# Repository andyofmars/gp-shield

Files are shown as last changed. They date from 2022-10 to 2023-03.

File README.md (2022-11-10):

# gp-shield
## A general purpose arduino-compatible shield for UTAS projects

<p float="left">
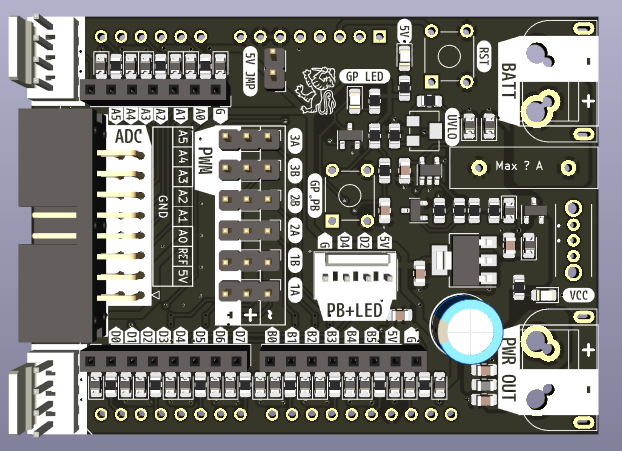
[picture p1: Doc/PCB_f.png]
  
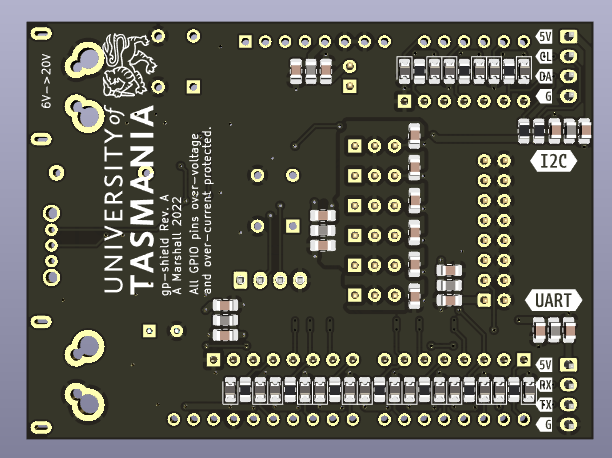
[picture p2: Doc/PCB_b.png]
   
</p>

## Overview
The shield is intended to be used as a general purpose shield for Arduino Uno compatible microcontroller development boards or as an interface between a development board and other custom electronics.

From previous projects we have identified multiple common issues when interfacing with common microcontroller development boards including the Arduino UNO and Xplained Mini series of development boards.
- Many development boards are sensitive to fluctuations in the power supply during programming and can become 'bricked'.
- A lack of protection on the Vin and 5V lines when being powered from a shield or other electronics makes them susceptible to damage.
- Due to the lack of protection and the large number of exposed GPIO pins it is easy to draw too much current or apply an overvoltage condition which will damage the microcontroller.

**See [Rugged Circuits](https://www.rugged-circuits.com/10-ways-to-destroy-an-arduino) for more detail on common issues with the Arduino UNO.**

To resolve these issue for most use cases and provide general functionality commonly needed in electronics projects we have developed the gp-shield to be used as the standard method of interfacing with Arduino UNO compatible development boards.

## Features
- Can be powered from external battery (~6V - 20V)
- On-board power supply with overvoltage (25V?), overcurrent (6A), and reverse polarity protection as well as adjustable undervoltage lockout and an on-board or external power switch.
- Onboard 5V regulation (up to 1A output) with circuitry with a jumper to isolate 5V from the development board.
- Overvoltage (~5.1V) and overcurrent (~30mA) protection on all GPIO pins when using the on-board headers and connectors.
- ICD style analogue outputs, PORTD and PORTB GPIO pins, 6 servo-style PWM outputs, UART, SPI and a high current output for powereing other electronics from the same supply with all of the built in seafty features.
- On-board microcontroller reset button
- On-board general purpose LED and push button

The board itself is 2-layers with double-sided load. All components use footprints suitable for hand-soldering. It is intended to be assembled in-house using pick-and-place machine and reflow soldering.

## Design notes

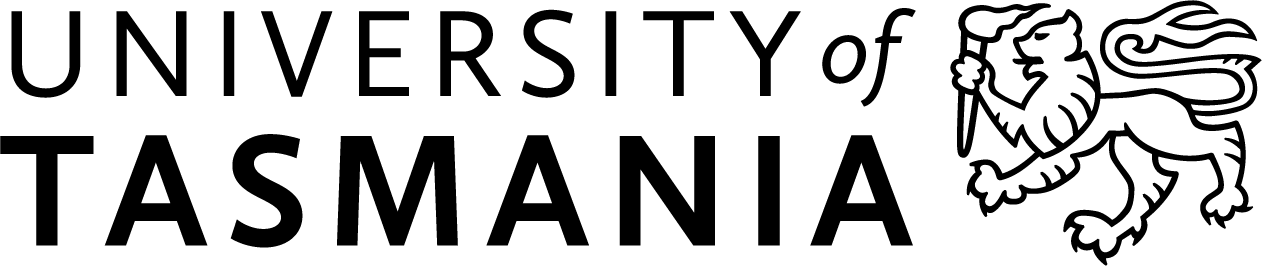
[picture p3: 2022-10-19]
Hardware/Electrical/gp-shield/Resource/UniTas_BM_H_Pos_Mono_RGB_2021@2x.png

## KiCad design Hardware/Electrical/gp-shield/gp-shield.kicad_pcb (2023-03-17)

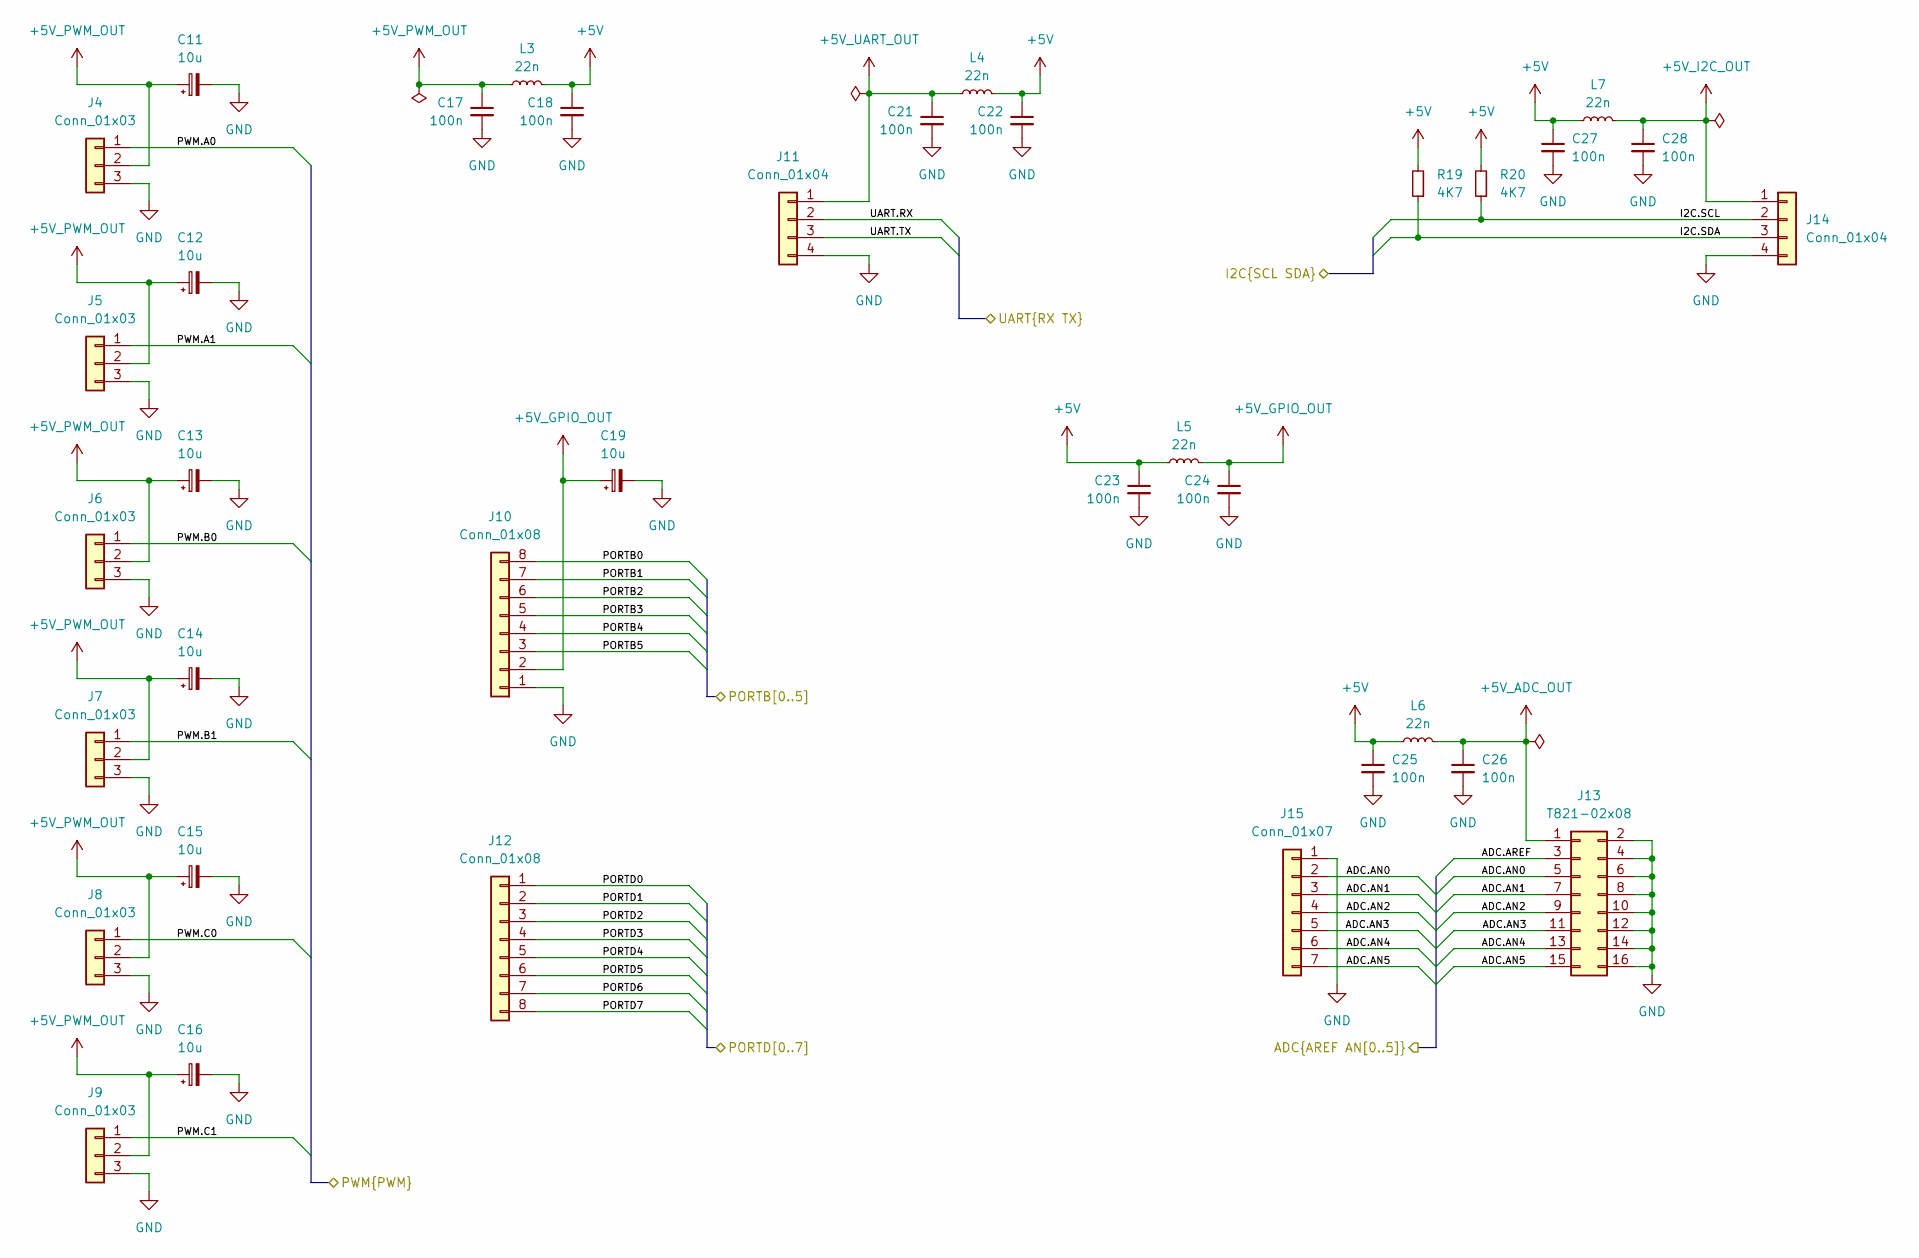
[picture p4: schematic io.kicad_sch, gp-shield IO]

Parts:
C11, C12, C13, C14, C15, C16, C19: 10u; C_0805_2012Metric_Pad1.18x1.45mm_HandSolder
C17, C18, C21, C22, C23, C24, C25, C26, C27, C28: 100n; C_0805_2012Metric_Pad1.18x1.45mm_HandSolder
J4, J5, J6, J7, J8, J9: Conn_01x03; PinHeader_1x03_P2.54mm_Vertical
J10, J12: Conn_01x08; PinSocket_1x08_P2.54mm_Vertical
J11, J14: Conn_01x04; Molex_KK-254_AE-6410-04A_1x04_P2.54mm_Vertical
J13: T821-02x08; IDC-Header_2x08_P2.54mm_Horizontal
J15: Conn_01x07; PinSocket_1x07_P2.54mm_Vertical
L3, L4, L5, L6, L7: 22n; L_0805_2012Metric_Pad1.15x1.40mm_HandSolder
R19, R20: 4K7; R_0805_2012Metric_Pad1.20x1.40mm_HandSolder

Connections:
+5V: C18.1, C22.1, C23.1, C25.1, C27.1, L3.1, L4.1, L5.2, L6.1, L7.1, R19.2, R20.2; also elsewhere on the board
+5V_ADC_OUT: C26.1, J13.1, L6.2
+5V_GPIO_OUT: C19.1, C24.1, J10.2, L5.1
+5V_I2C_OUT: C28.1, J14.1, L7.2
+5V_PWM_OUT: C11.1, C12.1, C13.1, C14.1, C15.1, C16.1, C17.1, J4.2, J5.2, J6.2, J7.2, J8.2, J9.2, L3.2
+5V_UART_OUT: C21.1, J11.1, L4.2
/IO/ADC.AN0: J13.5, J15.2; also elsewhere on the board
/IO/ADC.AN1: J13.7, J15.3; also elsewhere on the board
/IO/ADC.AN2: J13.9, J15.4; also elsewhere on the board
/IO/ADC.AN3: J13.11, J15.5; also elsewhere on the board
/IO/ADC.AN4: J13.13, J15.6; also elsewhere on the board
/IO/ADC.AN5: J13.15, J15.7; also elsewhere on the board
/IO/ADC.AREF: J13.3; also elsewhere on the board
/IO/I2C.SCL: J14.2, R20.1; also elsewhere on the board
/IO/I2C.SDA: J14.3, R19.1; also elsewhere on the board
/IO/PORTB0: J10.8; also elsewhere on the board
/IO/PORTB1: J10.7; also elsewhere on the board
/IO/PORTB2: J10.6; also elsewhere on the board
/IO/PORTB3: J10.5; also elsewhere on the board
/IO/PORTB4: J10.4; also elsewhere on the board
/IO/PORTB5: J10.3; also elsewhere on the board
/IO/PORTD0: J12.1; also elsewhere on the board
/IO/PORTD1: J12.2; also elsewhere on the board
/IO/PORTD2: J12.3; also elsewhere on the board
/IO/PORTD3: J12.4; also elsewhere on the board
/IO/PORTD4: J12.5; also elsewhere on the board
/IO/PORTD5: J12.6; also elsewhere on the board
/IO/PORTD6: J12.7; also elsewhere on the board
/IO/PORTD7: J12.8; also elsewhere on the board
/IO/PWM.A0: J4.1; also elsewhere on the board
/IO/PWM.A1: J5.1; also elsewhere on the board
/IO/PWM.B0: J6.1; also elsewhere on the board
/IO/PWM.B1: J7.1; also elsewhere on the board
/IO/PWM.C0: J8.1; also elsewhere on the board
/IO/PWM.C1: J9.1; also elsewhere on the board
/IO/UART.RX: J11.2; also elsewhere on the board
/IO/UART.TX: J11.3; also elsewhere on the board
GND: C11.2, C12.2, C13.2, C14.2, C15.2, C16.2, C17.2, C18.2, C19.2, C21.2, C22.2, C23.2, C24.2, C25.2, C26.2, C27.2, C28.2, J4.3, J5.3, J6.3, J7.3, J8.3, J9.3, J10.1, J11.4, J13.2, J13.4, J13.6, J13.8, J13.10, J13.12, J13.14, J13.16, J14.4, J15.1; also elsewhere on the board

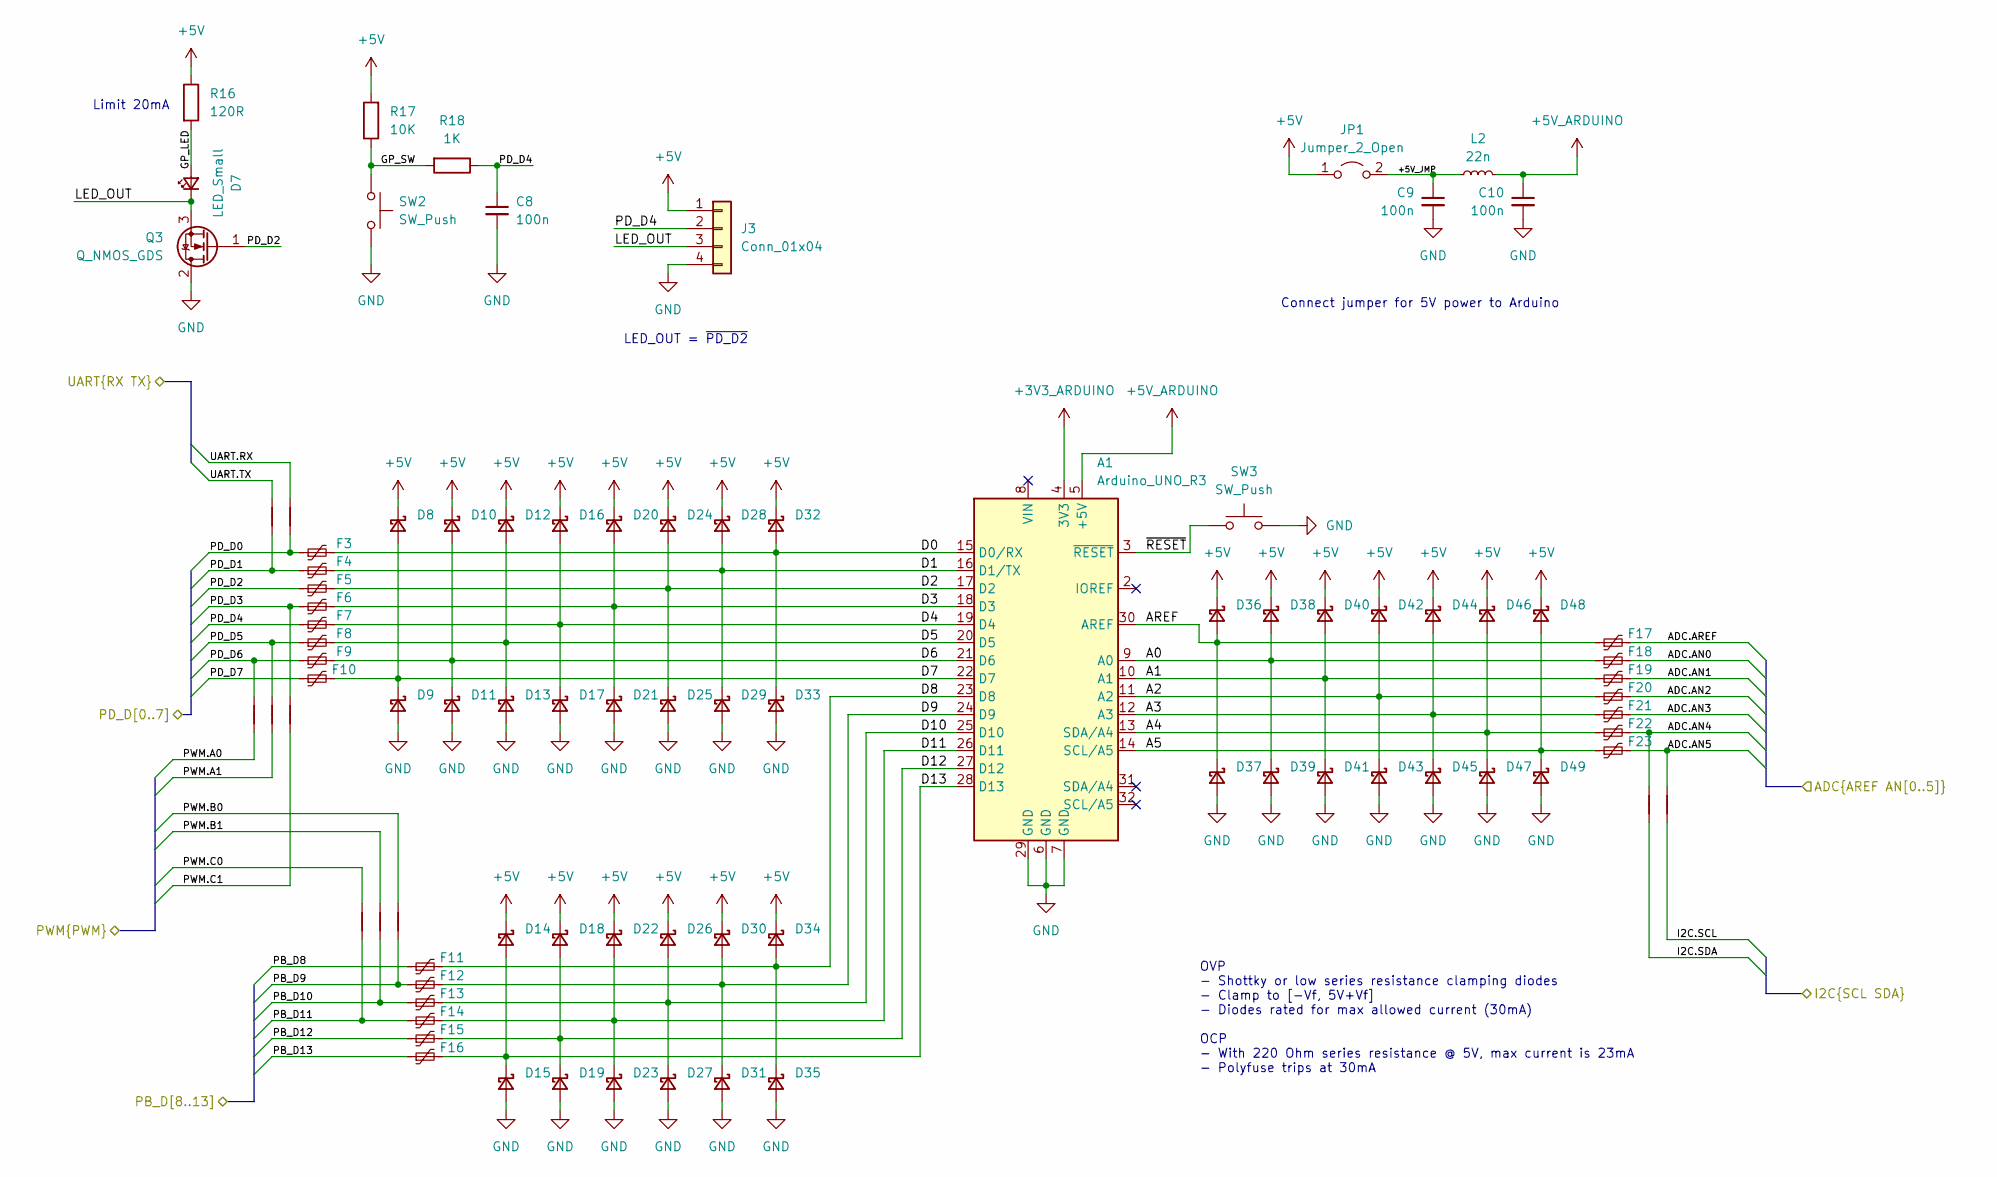
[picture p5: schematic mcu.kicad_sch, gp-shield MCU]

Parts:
A1: Arduino_UNO_R3
C8, C9, C10: 100n; C_0805_2012Metric_Pad1.18x1.45mm_HandSolder
D7: LED_Small; LED_0805_2012Metric_Pad1.15x1.40mm_HandSolder
D8, D9, D10, D11, D12, D13, D14, D15, D16, D17, D18, D19, D20, D21, D22, D23, D24, D25, D26, D27, D28, D29, D30, D31, D32, D33, D34, D35, D36, D37, D38, D39, D40, D41, D42, D43, D44, D45, D46, D47, D48, D49: D_Schottky_Small; D_0805_2012Metric_Pad1.15x1.40mm_HandSolder
F3, F4, F5, F6, F7, F8, F9, F10, F11, F12, F13, F14, F15, F16, F17, F18, F19, F20, F21, F22, F23: Polyfuse_Small; Fuse_0805_2012Metric_Pad1.15x1.40mm_HandSolder; Digikey Part No PRG18BB221MB1RB
J3: Conn_01x04; Molex_KK-254_AE-6410-04A_1x04_P2.54mm_Vertical
JP1: Jumper_2_Open; PinHeader_1x02_P2.54mm_Vertical
L2: 22n; L_0805_2012Metric_Pad1.15x1.40mm_HandSolder
NT1, NT2, NT3, NT4, NT5, NT6, NT7, NT8, NT9, NT10: NetTie_2; NetTie-2_THT_Pad0.3mm
Q3: Q_NMOS_GDS; SOT-23
R16: 120R; R_0805_2012Metric_Pad1.20x1.40mm_HandSolder
R17: 10K; R_0805_2012Metric_Pad1.20x1.40mm_HandSolder
R18: 1K; R_0805_2012Metric_Pad1.20x1.40mm_HandSolder
SW2, SW3: SW_Push; SW_TH_Tactile_Omron_B3F-10xx

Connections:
+3V3_ARDUINO: A1.4 (3V3)
+5V: D8.1 (K), D10.1 (K), D12.1 (K), D14.1 (K), D16.1 (K), D18.1 (K), D20.1 (K), D22.1 (K), D24.1 (K), D26.1 (K), D28.1 (K), D30.1 (K), D32.1 (K), D34.1 (K), D36.1 (K), D38.1 (K), D40.1 (K), D42.1 (K), D44.1 (K), D46.1 (K), D48.1 (K), J3.1, JP1.1 (A), R16.1, R17.2; also elsewhere on the board
+5V_ARDUINO: A1.5 (+5V), C10.1, L2.1
/IO/ADC.AN0: F18.2; also elsewhere on the board
/IO/ADC.AN1: F19.2; also elsewhere on the board
/IO/ADC.AN2: F20.2; also elsewhere on the board
/IO/ADC.AN3: F21.2; also elsewhere on the board
/IO/ADC.AN4: F22.2, NT9.2; also elsewhere on the board
/IO/ADC.AN5: F23.2, NT10.2; also elsewhere on the board
/IO/ADC.AREF: F17.2; also elsewhere on the board
/IO/I2C.SCL: NT10.1; also elsewhere on the board
/IO/I2C.SDA: NT9.1; also elsewhere on the board
/IO/PORTB0: F11.1; also elsewhere on the board
/IO/PORTB1: F12.1, NT8.1; also elsewhere on the board
/IO/PORTB2: F13.1, NT7.1; also elsewhere on the board
/IO/PORTB3: F14.1, NT6.1; also elsewhere on the board
/IO/PORTB4: F15.1; also elsewhere on the board
/IO/PORTB5: F16.1; also elsewhere on the board
/IO/PORTD0: F3.1, NT4.1; also elsewhere on the board
/IO/PORTD1: F4.1, NT2.1; also elsewhere on the board
/IO/PORTD2: F5.1, Q3.1 (G); also elsewhere on the board
/IO/PORTD3: F6.1, NT5.2; also elsewhere on the board
/IO/PORTD4: C8.1, F7.1, J3.2, R18.1; also elsewhere on the board
/IO/PORTD5: F8.1, NT3.2; also elsewhere on the board
/IO/PORTD6: F9.1, NT1.2; also elsewhere on the board
/IO/PORTD7: F10.1; also elsewhere on the board
/IO/PWM.A0: NT1.1; also elsewhere on the board
/IO/PWM.A1: NT3.1; also elsewhere on the board
/IO/PWM.B0: NT8.2; also elsewhere on the board
/IO/PWM.B1: NT7.2; also elsewhere on the board
/IO/PWM.C0: NT6.2; also elsewhere on the board
/IO/PWM.C1: NT5.1; also elsewhere on the board
/IO/UART.RX: NT4.2; also elsewhere on the board
/IO/UART.TX: NT2.2; also elsewhere on the board
/MCU/+5V_JMP: C9.1, JP1.2 (B), L2.2
/MCU/A0: A1.9 (A0), D38.2 (A), D39.1 (K), F18.1
/MCU/A1: A1.10 (A1), D40.2 (A), D41.1 (K), F19.1
/MCU/A2: A1.11 (A2), D42.2 (A), D43.1 (K), F20.1
/MCU/A3: A1.12 (A3), D44.2 (A), D45.1 (K), F21.1
/MCU/A4: A1.13 (SDA/A4), D46.2 (A), D47.1 (K), F22.1
/MCU/A5: A1.14 (SCL/A5), D48.2 (A), D49.1 (K), F23.1
/MCU/AREF: A1.30 (AREF), D36.2 (A), D37.1 (K), F17.1
/MCU/D0: A1.15 (D0/RX), D32.2 (A), D33.1 (K), F3.2
/MCU/D1: A1.16 (D1/TX), D28.2 (A), D29.1 (K), F4.2
/MCU/D2: A1.17 (D2), D24.2 (A), D25.1 (K), F5.2
/MCU/D3: A1.18 (D3), D20.2 (A), D21.1 (K), F6.2
/MCU/D4: A1.19 (D4), D16.2 (A), D17.1 (K), F7.2
/MCU/D5: A1.20 (D5), D12.2 (A), D13.1 (K), F8.2
/MCU/D6: A1.21 (D6), D10.2 (A), D11.1 (K), F9.2
/MCU/D7: A1.22 (D7), D8.2 (A), D9.1 (K), F10.2
/MCU/D8: A1.23 (D8), D34.2 (A), D35.1 (K), F11.2
/MCU/D9: A1.24 (D9), D30.2 (A), D31.1 (K), F12.2
/MCU/D10: A1.25 (D10), D26.2 (A), D27.1 (K), F13.2
/MCU/D11: A1.26 (D11), D22.2 (A), D23.1 (K), F14.2
/MCU/D12: A1.27 (D12), D18.2 (A), D19.1 (K), F15.2
/MCU/D13: A1.28 (D13), D14.2 (A), D15.1 (K), F16.2
/MCU/GP_LED: D7.2 (A), R16.2
/MCU/GP_SW: R17.1, R18.2, SW2.1
/MCU/LED_OUT: D7.1 (K), J3.3, Q3.3 (S)
/MCU/~RESET: A1.3 (~RESET), SW3.1
GND: A1.6 (GND), A1.7 (GND), A1.29 (GND), C8.2, C9.2, C10.2, D9.2 (A), D11.2 (A), D13.2 (A), D15.2 (A), D17.2 (A), D19.2 (A), D21.2 (A), D23.2 (A), D25.2 (A), D27.2 (A), D29.2 (A), D31.2 (A), D33.2 (A), D35.2 (A), D37.2 (A), D39.2 (A), D41.2 (A), D43.2 (A), D45.2 (A), D47.2 (A), D49.2 (A), J3.4, Q3.2 (D), SW2.2, SW3.2; also elsewhere on the board

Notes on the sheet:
LED_OUT = ~{PD_D2}
OVP - Shottky or low series resistance clamping diodes - Clamp to [-Vf, 5V+Vf] - Diodes rated for max allowed current (30mA) OCP - With 220 Ohm series resistance @ 5V, max current is 23mA - Polyfuse trips at 30mA
Limit 20mA
Connect jumper for 5V power to Arduino

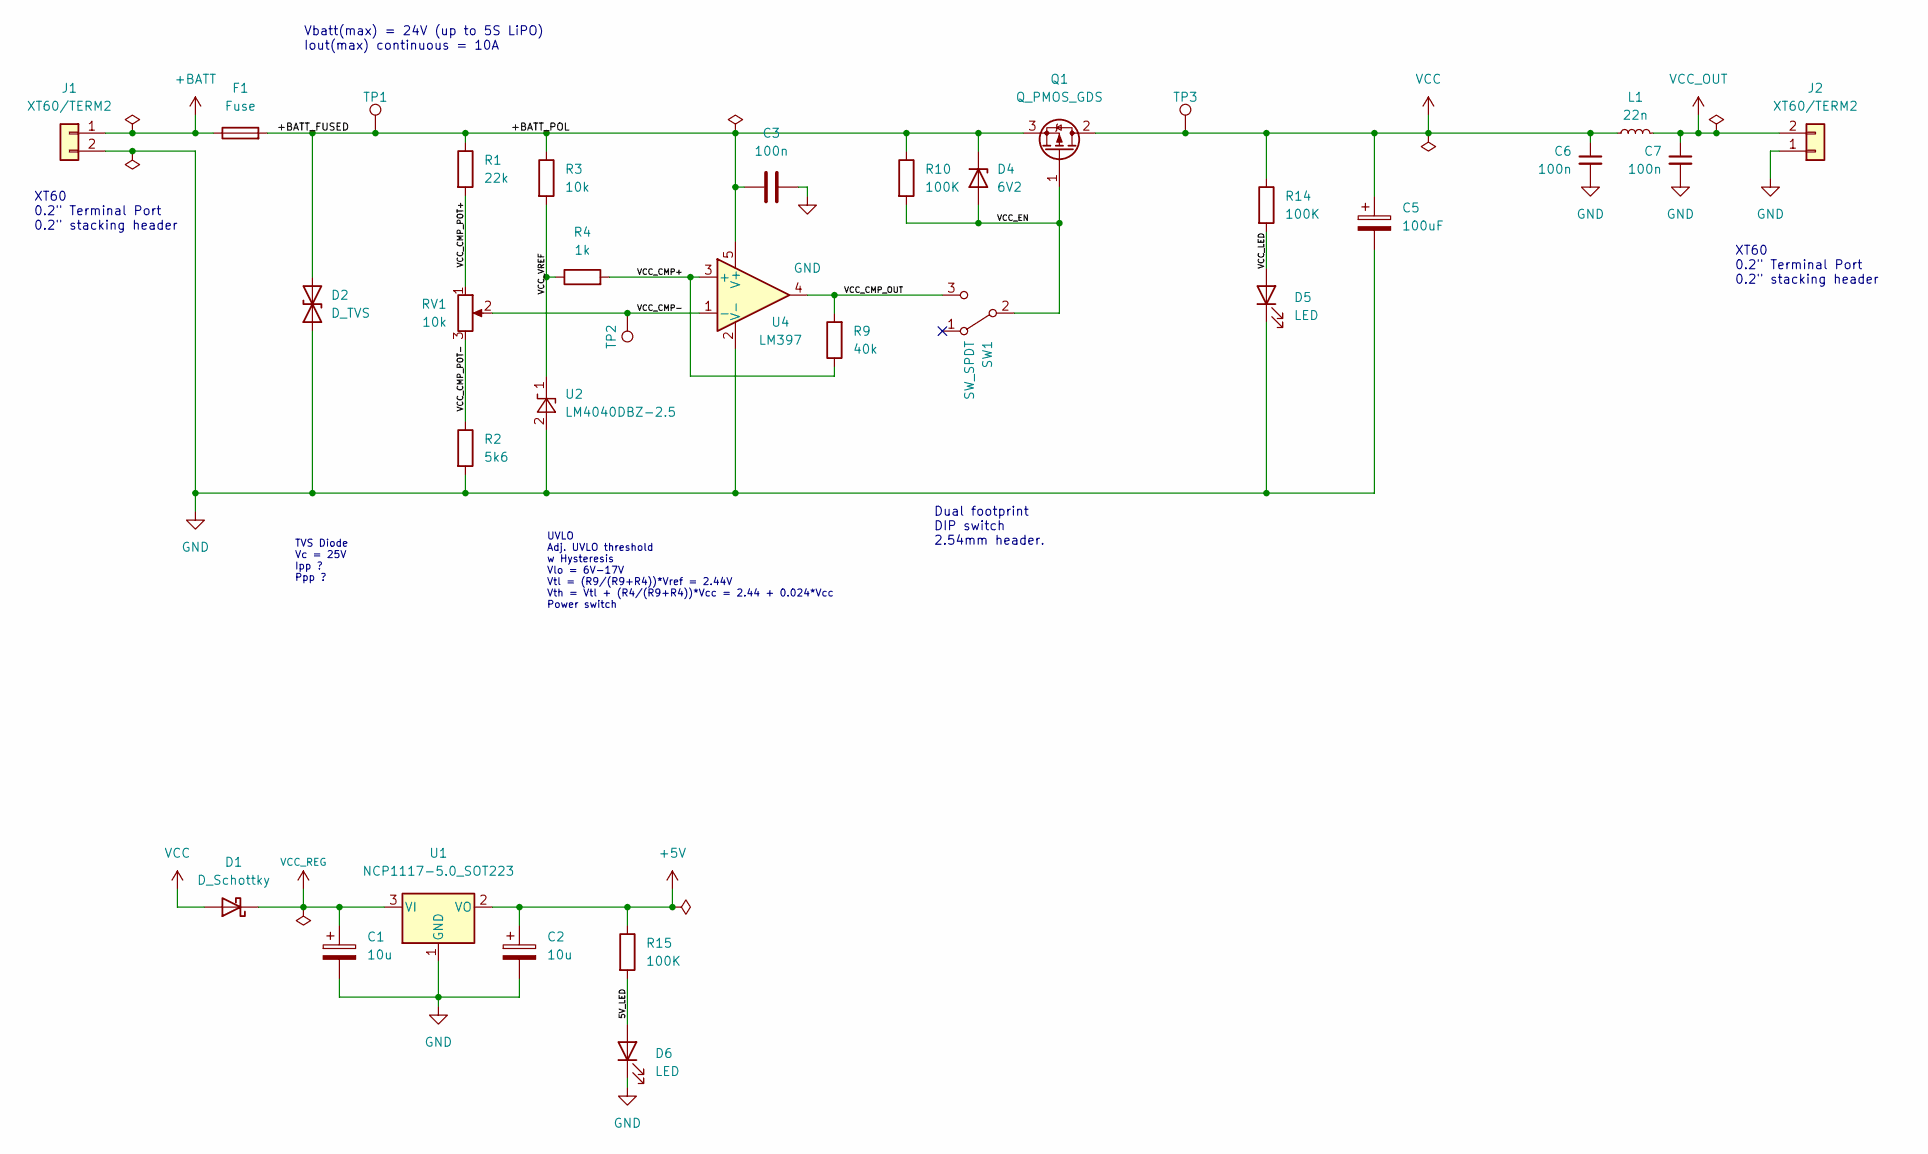
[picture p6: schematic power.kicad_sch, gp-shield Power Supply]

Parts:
C1, C2: 10u; C_0805_2012Metric_Pad1.18x1.45mm_HandSolder
C3, C6, C7: 100n; C_0805_2012Metric_Pad1.18x1.45mm_HandSolder
C5: 100uF; CP_Radial_D8.0mm_P3.50mm
D1: D_Schottky; D_0805_2012Metric_Pad1.15x1.40mm_HandSolder
D2: D_TVS; D_SMA
D4: 6V2; D_0805_2012Metric_Pad1.15x1.40mm_HandSolder
D5, D6: LED; LED_0805_2012Metric_Pad1.15x1.40mm_HandSolder
F1: Fuse; Fuseholder_Littelfuse_445_030_series_5x20mm
J1, J2: XT60/TERM2; Combined_TerminalBlock_5.08_XT60_2Row0.2Header
L1: 22n; L_0805_2012Metric_Pad1.15x1.40mm_HandSolder
Q1: Q_PMOS_GDS; TO-252-3_TabPin2
R1: 22k; R_0805_2012Metric_Pad1.20x1.40mm_HandSolder
R2: 5k6; R_0805_2012Metric_Pad1.20x1.40mm_HandSolder
R3: 10k; R_0805_2012Metric_Pad1.20x1.40mm_HandSolder
R4: 1k; R_0805_2012Metric_Pad1.20x1.40mm_HandSolder
R9: 40k; R_0805_2012Metric_Pad1.20x1.40mm_HandSolder
R10, R14, R15: 100K; R_0805_2012Metric_Pad1.20x1.40mm_HandSolder
RV1: 10k; Potentiometer_Bourns_3214W_Vertical
SW1: SW_SPDT; OS102011MA1_SPDT_ESwitch
TP1, TP2, TP3: TestPoint; TestPoint_THTPad_D2.0mm_Drill1.0mm
U1: NCP1117-5.0_SOT223; SOT-223-3_TabPin2
U2: LM4040DBZ-2.5; SOT-23
U4: LM397; SOT-23-5

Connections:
+5V: C2.1, R15.1, U1.2 (VO); also elsewhere on the board
+BATT: F1.1, J1.1
/Power/5V_LED: D6.2 (A), R15.2
/Power/+BATT_FUSED: C3.1, D2.2 (A2), D4.1 (K), F1.2, Q1.3 (S), R1.1, R3.1, R10.1, TP1.1, U4.5 (V+)
/Power/VCC_CMP+: R4.2, R9.1, U4.3 (+)
/Power/VCC_CMP-: RV1.2, TP2.1, U4.1 (-)
/Power/VCC_CMP_OUT: R9.2, SW1.3 (C), U4.4
/Power/VCC_CMP_POT+: R1.2, RV1.1
/Power/VCC_CMP_POT-: R2.1, RV1.3
/Power/VCC_EN: D4.2 (A), Q1.1 (G), R10.2, SW1.2 (B)
/Power/VCC_LED: D5.2 (A), R14.2
/Power/VCC_VREF: R3.2, R4.1, U2.1 (K)
GND: C1.2, C2.2, C3.2, C5.2, C6.2, C7.2, D2.1 (A1), D5.1 (K), D6.1 (K), J1.2, J2.1, R2.2, U1.1 (GND), U2.2 (A), U4.2 (V-); also elsewhere on the board
VCC: C5.1, C6.1, D1.2 (A), L1.2, Q1.2 (D), R14.1, TP3.1
VCC_OUT: C7.1, J2.2, L1.1
VCC_REG: C1.1, D1.1 (K), U1.3 (VI)

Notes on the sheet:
XT60 0.2" Terminal Port 0.2" stacking header
Dual footprint DIP switch 2.54mm header.
UVLO Adj. UVLO threshold w Hysteresis Vlo = 6V-17V Vtl = (R9/(R9+R4))*Vref = 2.44V Vth = Vtl + (R4/(R9+R4))*Vcc = 2.44 + 0.024*Vcc Power switch
Vbatt(max) = 24V (up to 5S LiPO) Iout(max) continuous = 10A
TVS Diode Vc = 25V Ipp ? Ppp ?

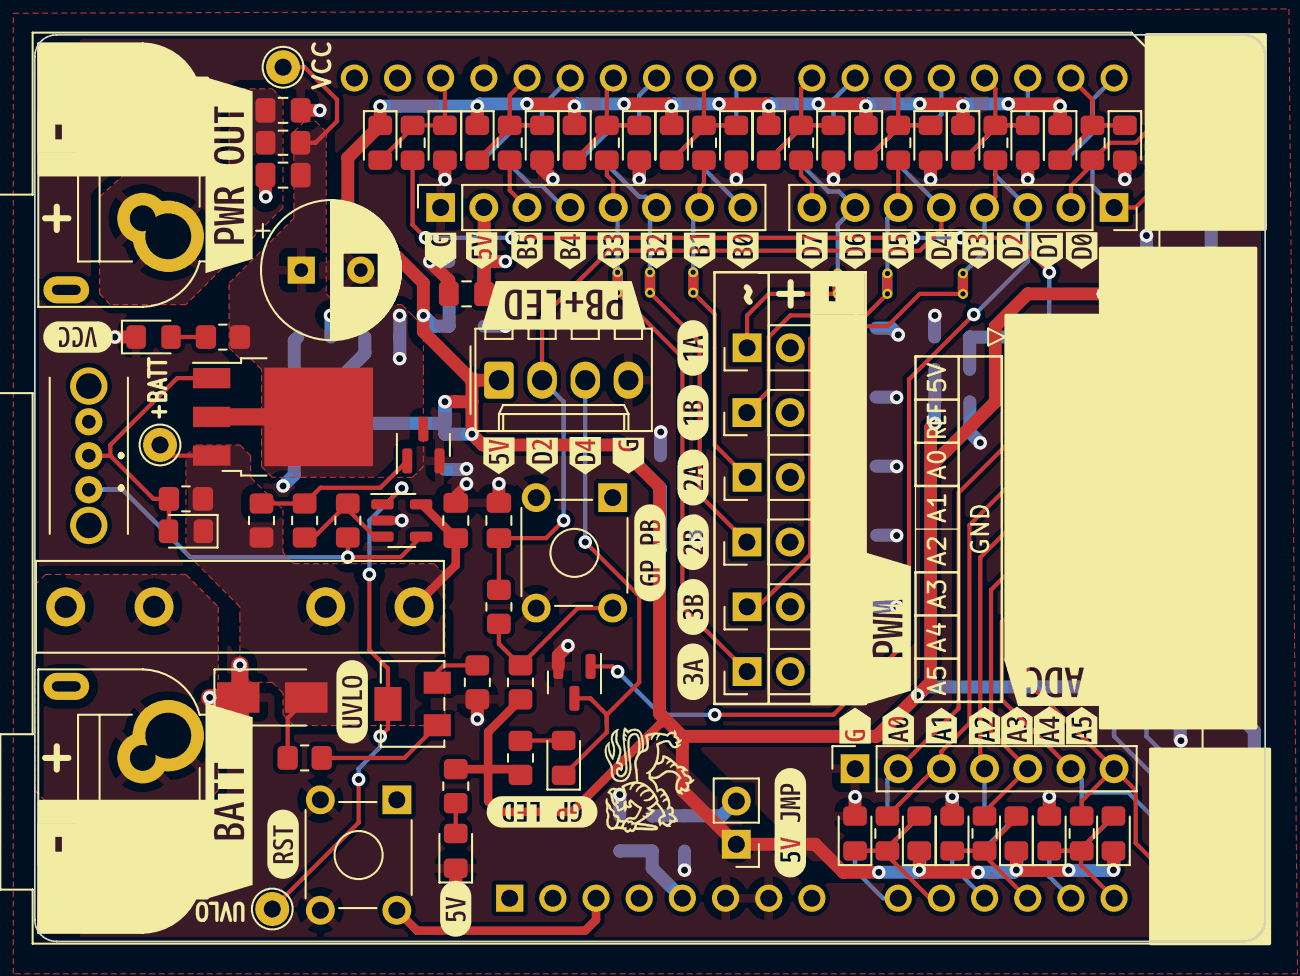
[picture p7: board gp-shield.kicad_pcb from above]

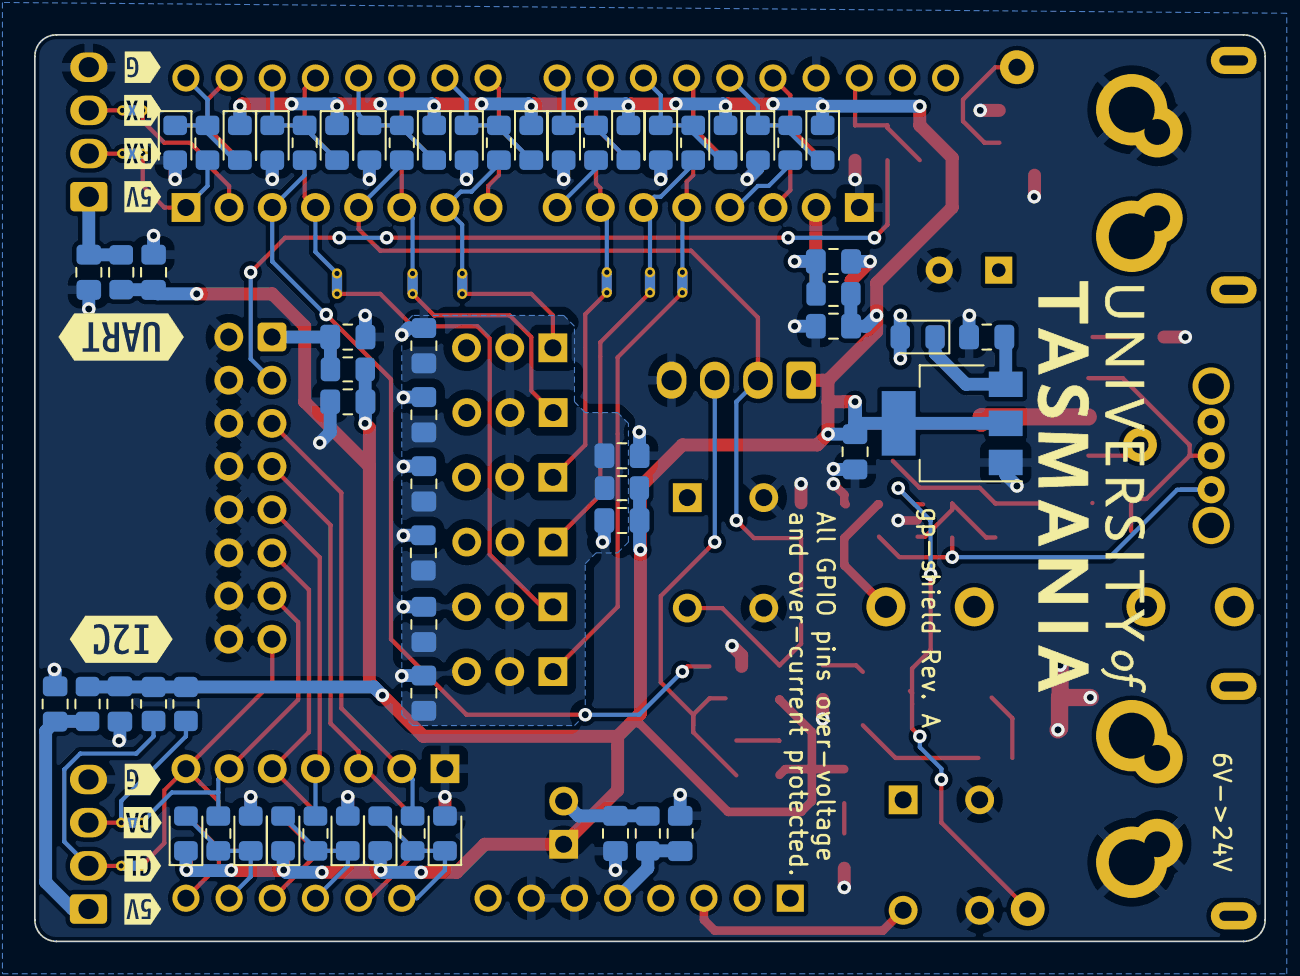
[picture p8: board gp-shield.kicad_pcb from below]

Board: 2 copper layers, 72.4 x 53.3 mm, 213 parts (71 on the bottom side), 79 nets.

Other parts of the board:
kibuzzard-636B2D3F: G***; kibuzzard-636B2D3F
kibuzzard-636B3B8D: G***; kibuzzard-636B3B8D
kibuzzard-636B3BDA: G***; kibuzzard-636B3BDA
kibuzzard-636B3BFE: G***; kibuzzard-636B3BFE
kibuzzard-636B3C0D: G***; kibuzzard-636B3C0D
kibuzzard-636B3C1B: G***; kibuzzard-636B3C1B
kibuzzard-636B3C06: G***; kibuzzard-636B3C06
kibuzzard-636B3C14: G***; kibuzzard-636B3C14
kibuzzard-636B3C68: G***; kibuzzard-636B3C68
kibuzzard-636B3D37: G***; kibuzzard-636B3D37
kibuzzard-636B29B0: G***; kibuzzard-636B29B0
kibuzzard-636B29F7: G***; kibuzzard-636B29F7
kibuzzard-636B37C6: G***; kibuzzard-636B37C6
kibuzzard-636B37CC: G***; kibuzzard-636B37CC
kibuzzard-636B37D3: G***; kibuzzard-636B37D3
kibuzzard-636B37D9: G***; kibuzzard-636B37D9
kibuzzard-636B37E0: G***; kibuzzard-636B37E0
kibuzzard-636B37FB: G***; kibuzzard-636B37FB
kibuzzard-636B38AF: G***; kibuzzard-636B38AF
kibuzzard-636B41C3: G***; kibuzzard-636B41C3
kibuzzard-636B290E: G***; kibuzzard-636B290E
kibuzzard-636B388A: G***; kibuzzard-636B388A
kibuzzard-636B437B: G***; kibuzzard-636B437B
kibuzzard-636B2900: G***; kibuzzard-636B2900
kibuzzard-636B3819: G***; kibuzzard-636B3819
kibuzzard-636B3822: G***; kibuzzard-636B3822
kibuzzard-636B3829: G***; kibuzzard-636B3829
kibuzzard-636B3831: G***; kibuzzard-636B3831
kibuzzard-636B3838: G***; kibuzzard-636B3838
kibuzzard-636B3843: G***; kibuzzard-636B3843
kibuzzard-636B3849: G***; kibuzzard-636B3849
kibuzzard-636B3891: G***; kibuzzard-636B3891
kibuzzard-636C5C0D: G***; kibuzzard-636C5C0D
kibuzzard-636C5C1C: G***; kibuzzard-636C5C1C
kibuzzard-636C5C4A: G***; kibuzzard-636C5C4A
kibuzzard-636C5C28: G***; kibuzzard-636C5C28
kibuzzard-636C5C36: G***; kibuzzard-636C5C36
kibuzzard-636C5C55: G***; kibuzzard-636C5C55
kibuzzard-636C5C62: G***; kibuzzard-636C5C62
kibuzzard-636C5C70: G***; kibuzzard-636C5C70
kibuzzard-636C54A9: G***; kibuzzard-636C54A9
kibuzzard-636C5470: G***; kibuzzard-636C5470
kibuzzard-63524FB6: G***; kibuzzard-63524FB6
kibuzzard-63524FC9: G***; kibuzzard-63524FC9
kibuzzard-63527D9E: G***; kibuzzard-63527D9E
kibuzzard-63527D35: G***; kibuzzard-63527D35
kibuzzard-63527DAD: G***; kibuzzard-63527DAD
kibuzzard-635273D0: G***; kibuzzard-635273D0
kibuzzard-635273DC: G***; kibuzzard-635273DC
kibuzzard-6352498A: G***; kibuzzard-6352498A
kibuzzard-6352739F: G***; kibuzzard-6352739F
kibuzzard-63524950: G***; kibuzzard-63524950
kibuzzard-63524966: G***; kibuzzard-63524966
kibuzzard-63524973: G***; kibuzzard-63524973
kibuzzard-63524980: G***; kibuzzard-63524980
kibuzzard-63524994: G***; kibuzzard-63524994
kibuzzard-63527359: G***; kibuzzard-63527359
kibuzzard-63527364: G***; kibuzzard-63527364

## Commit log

2022-10-20 Added PWM connectors, subnet labels, arduino power supply protection
    [gp-shield.kicad_sch, mcu.kicad_sch, power.kicad_sch]
2022-10-22 Major revisions to PCB layout
    - near final layout
    - prototype version of silkscreen
    - removed 3.3V reg
    [gp-shield.kicad_pcb, gp-shield.kicad_sch, io.kicad_sch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]
2022-10-23 Added net classes
    [gp-shield.kicad_pcb, gp-shield.kicad_sch, io.kicad_sch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]
2022-10-27 Added spice models of power supply
    5v-reg in progress
2022-10-27 Updated PCB
    - changed switch footprint
    - created footprint library for E switch varieties
    [gp-shield.kicad_pcb, gp-shield.kicad_sch, io.kicad_sch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]
2022-10-27 Updated Power supply design
    Simplified reverse polarity and overvoltage protection
    Added adjustable UVLO with precision Vref
    Added hysteresis to comparators
    Added precision reference to 5V cmp circuit.
    [gp-shield.kicad_sch, power.kicad_sch]
2022-10-27 Added clamping diodes
    Replaced zener regulator protection for GPIO with bidierectional schottky clamping diodes
    [gp-shield.kicad_sch, mcu.kicad_sch]
2022-11-03 Major revisions
    [gp-shield.kicad_pcb, gp-shield.kicad_sch, io.kicad_sch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]
2022-11-03 Changes to component footprints
    [gp-shield.kicad_sch, power.kicad_sch]
2022-11-09 Major PCB changes
    Added combined footprint for XT60 and terminal port.
    Fixed polarity of Batt and PWR_out connectors.
    Standardised polarity markers to show negative on white.
    Moved Port D and Port B connectors to be inline with existing arduino connectors. Removed extra pins.
    Added analogue in-line output.
    Adjusted component placement for more space around power supply and GP PB and LED.
    Draft version of track routing - incomplete.
    [gp-shield.kicad_pcb, gp-shield.kicad_sch, io.kicad_sch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]
2022-11-10 Complete draft PCB layout
    Added updated renders to doc.
    Added some documentation to schematic
    complete PCB layout with some revisions still needed
    [gp-shield.kicad_pcb, gp-shield.kicad_sch, io.kicad_sch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]
2022-11-10 Minor changes to silkscreen and documentation
    [gp-shield.kicad_pcb]
2022-11-10 Added small radius to board edges
    [gp-shield.kicad_pcb]
2022-11-10 Additional 3d models
    [gp-shield.kicad_pcb]
2022-11-10 Added symbol and footprint for gp-shield headers
2022-11-24 Updated footprints and PCB layout
    Updated reverse polarity and overvoltage to use bidirectional TVS diode
    Changed footprint of TVS diode
    Changed footprint of fuse to proper 5x20mm fuse holder
    Changed footprint of PMOS high side switch to DPAK
    Updated layout with Vreg on backside
    [gp-shield.kicad_pcb, gp-shield.kicad_sch, power.kicad_sch]
2022-12-01 Changes to board setup and rules
    Changed to White soldermask with Black silkscreen.
    Tweaked Terminal port dual footprint
    Adjusted rules for courtyard clearance
    [gp-shield.kicad_pcb]
2022-12-01 Removed net ties from BOM
    [mcu.kicad_sch]
2022-12-01 Minor cosmetic imporvements
    title block and colour theme
    [gp-shield.kicad_pcb, gp-shield.kicad_sch, io.kicad_sch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]
2022-12-02 Minor tweaks to annotation
    [mcu.kicad_sch, power.kicad_sch]
2023-02-24 Added test points for key power signals
    [gp-shield.kicad_pcb, gp-shield.kicad_sch, power.kicad_sch]
2023-02-24 Minor annotation fixes from merge
    [power.kicad_sch]
2023-03-17 Minor changes to annotation and silkscreen
    [gp-shield.kicad_pcb, power.kicad_sch]
